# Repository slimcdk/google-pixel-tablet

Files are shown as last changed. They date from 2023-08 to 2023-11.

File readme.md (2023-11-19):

# Google Pixel Tablet

## Wall Mount (Version 2)



### Parts
7x M3x12mm countersunk. \
7x M3 nuts (<3mm thick). \
16x 12x5x3 cube magnets. \
2x M4 countersunk self tapping screw.

https://www.digikey.dk/da/products/detail/mill-max-manufacturing-corp/0853-0-15-20-82-14-11-0/2403178

## Base stand
### Disassembly

1) Rubber feet (E12) is held on with double sided adhesive. A gentle pull releases it.



2) Metal bracket (EW M2-1) is fastened with five Torx T7H screws (color coded magenta).



3) To EW M2-1 is main PCB attached. I assume this is the speaker driver. The 5-pin connector is for the speaker units. The smaller flex cable connects to the daughter PCB that mates with the tablet when it is docked.



4) Four Torx T6H screws (color coded green) fastens the magnetic face plate (TL-A2). The two in the front are easy to reach, however the two in the back are rather hard to reach. It requires a at least 70mm long screw driver (max 7mm) to reach them. The magnets are quite close and they will easily catch the screws at the bottom.



5) Face plate (TL-A2) lifts up.



6) The three main pieces.



### Magnet placements

The back has a total of eight magnet-pairs glued in place. Each pair has a thin metal backplate. I assume this is something that improves the magnetization.





A scan of the plate and a draw up in Freecad gives the exact locations of the magnets relative to the quick-disconnect port.



## Quick-disconnect connector

Disassembly and probing the connections reveals that the base stand forwards 12VDC to the tablet on the two outer most connector pads. The tablet will charge just fine if provided with 12VDC only.



The connector pair in the middle carry data signals. The protocol is still undetermined but it however seem like some sort of differential signalling.



Protocol is USB (maybe 2.0?), but is non-standard as logic levels are 3.3V and supply is 12V. It is undetermined if the circuitry is 5V tolerant. A connected ESP32-S3 appear as a serial device. The base station shows as Amlogic Korlan device.



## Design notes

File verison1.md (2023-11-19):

## Wall Mount Version 1



### Parts
7x M3x12mm countersunk. \
7x M3 nuts (<3mm thick). \
16x 12x5x3 cube magnets. \
2x M4 countersunk self tapping screw.

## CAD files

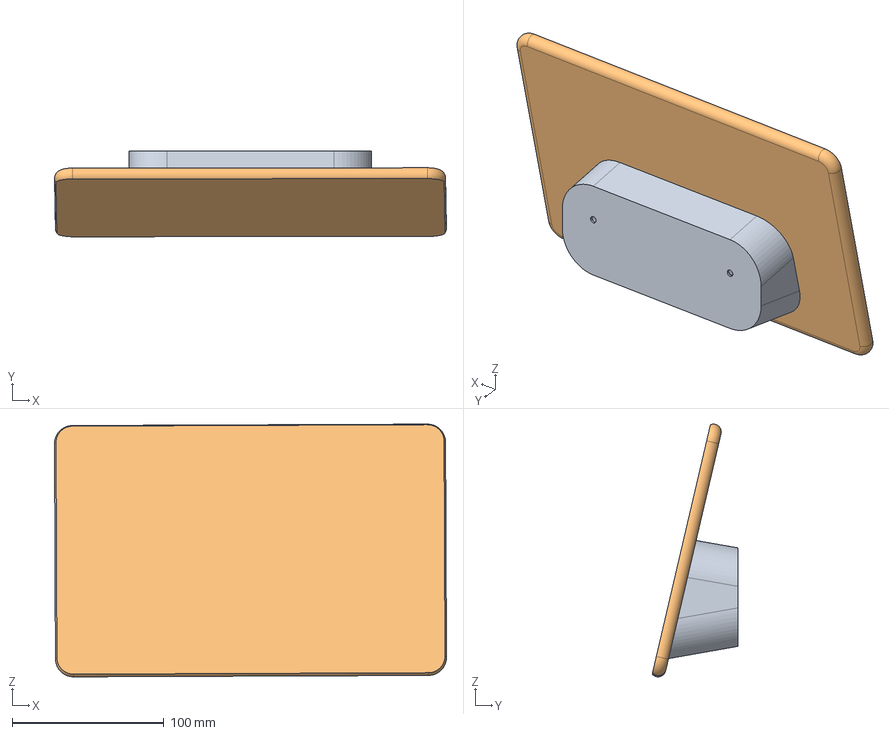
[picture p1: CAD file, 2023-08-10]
mechanics/assembly.FCStd
258.6 x 56.5 x 166.8 mm
wall-mount_001
pixel-tablet_001
M3x12-Screw
M3x12-Screw001
M3x12-Screw002
M3x12-Screw003
M3x12-Screw004
M3x12-Screw005
M3x12-Screw006

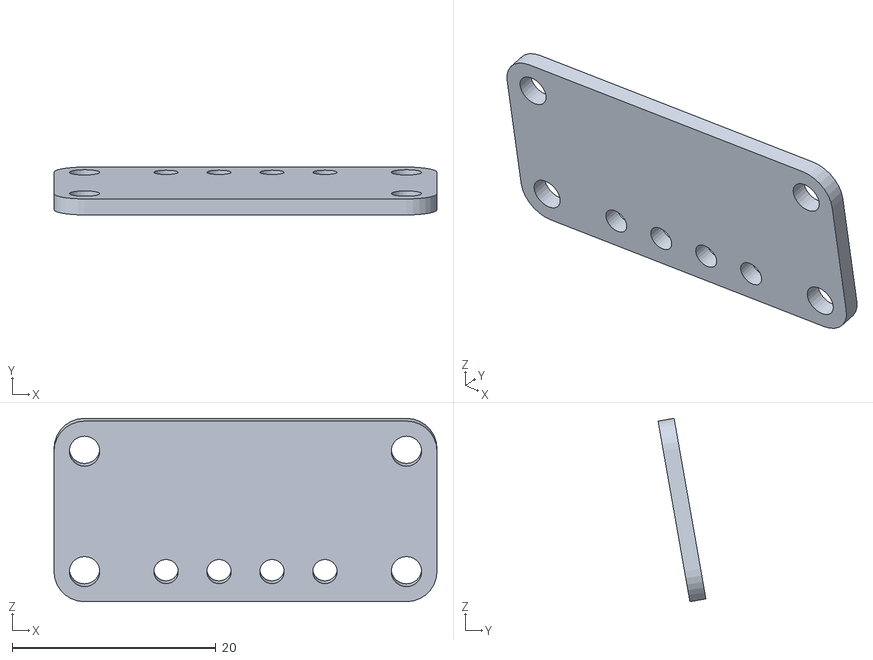
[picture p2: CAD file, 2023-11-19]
3d-print-files/v2-daughter-board.stl
37.6 x 4.70 x 18.0

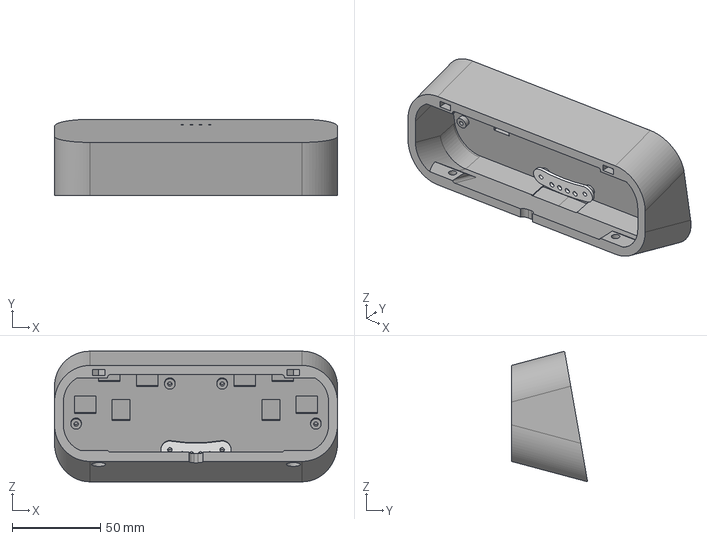
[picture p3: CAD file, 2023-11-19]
mechanics/wall-mount-v2.FCStd
160.0 x 43.1 x 73.9 mm
Housing

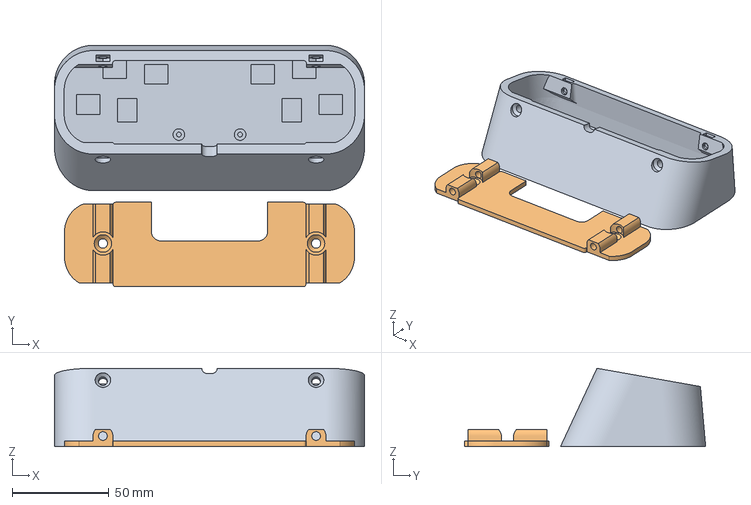
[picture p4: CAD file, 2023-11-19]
3d-print-files/v2-prusaslicer-setup.3mf
160.0 x 124.6 x 40.5 mm
v2-housing.stl
v2-mouting-plate.stl

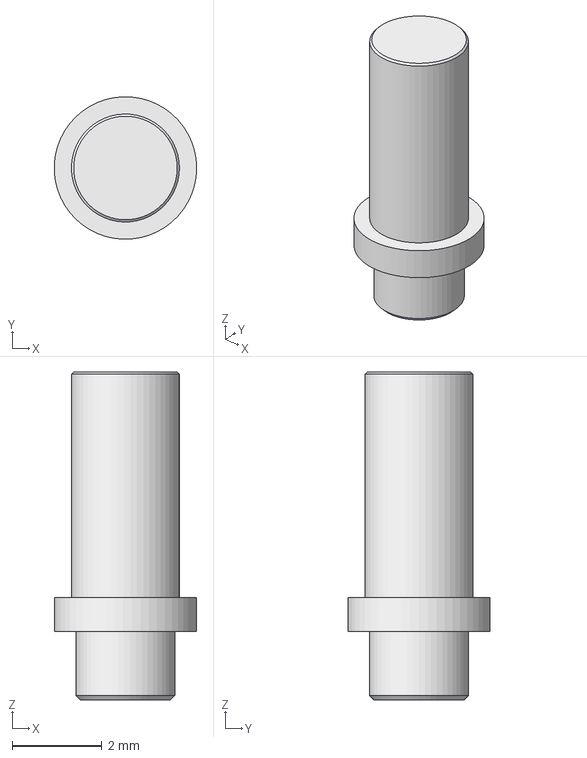
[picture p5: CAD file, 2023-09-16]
mechanics/pogo-pin.FCStd
3.18 x 3.18 x 7.32 mm

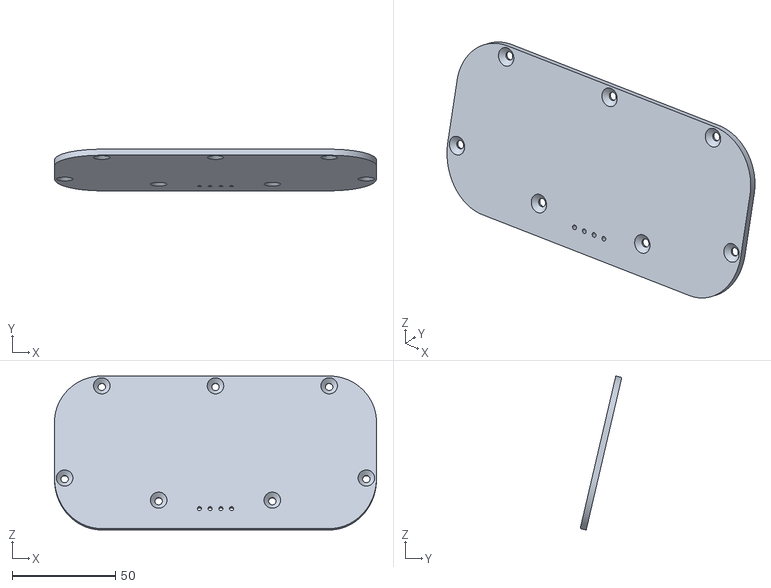
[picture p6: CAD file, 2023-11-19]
3d-print-files/v1-face-panel.stl
155.8 x 20.2 x 74.5

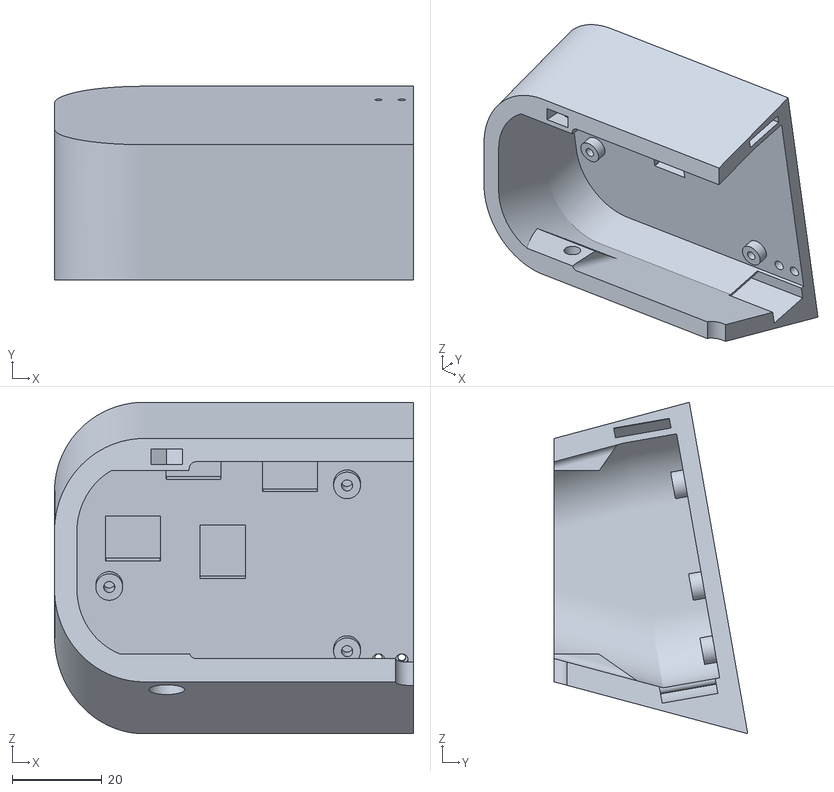
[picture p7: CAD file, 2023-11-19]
3d-print-files/wall-mount-v2-HousingPocket030.stl
80.0 x 43.1 x 73.9

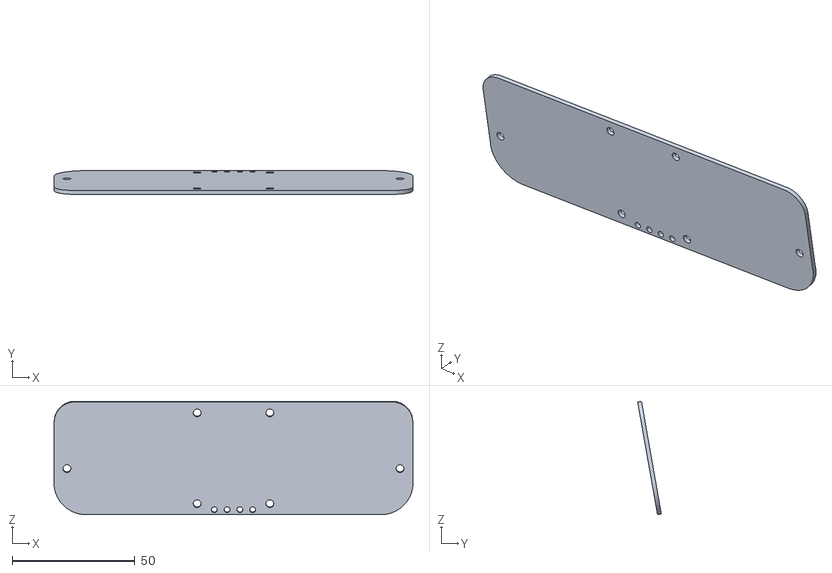
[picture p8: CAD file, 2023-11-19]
3d-print-files/wall-mount-v2-Board.stl
146.2 x 9.66 x 46.1

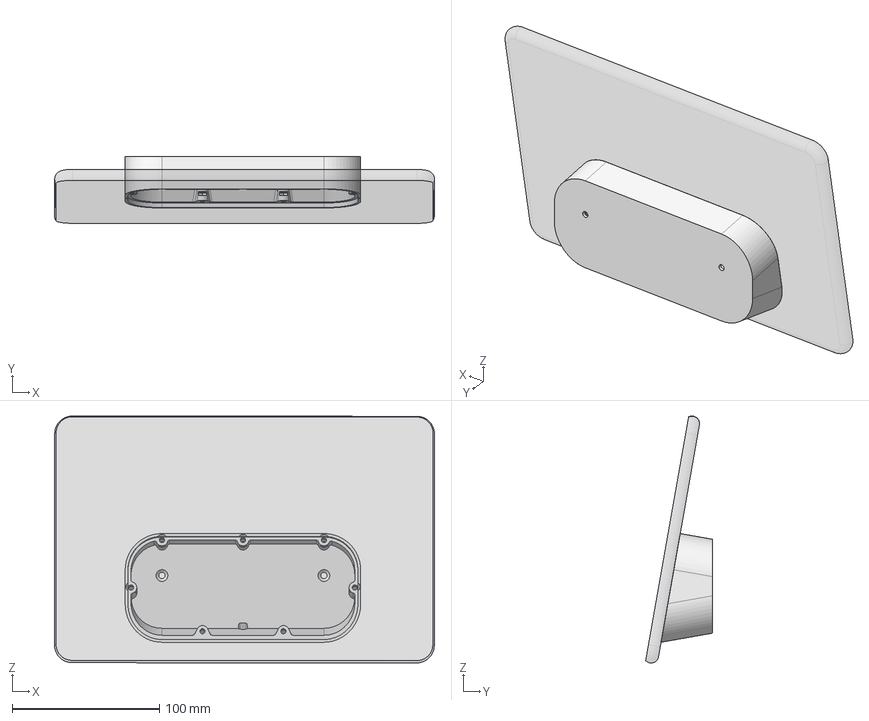
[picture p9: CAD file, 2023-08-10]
mechanics/wall-mount-proto.FCStd
258.1 x 45.3 x 167.8 mm
pixel-tablet_001
Base
Face Plate

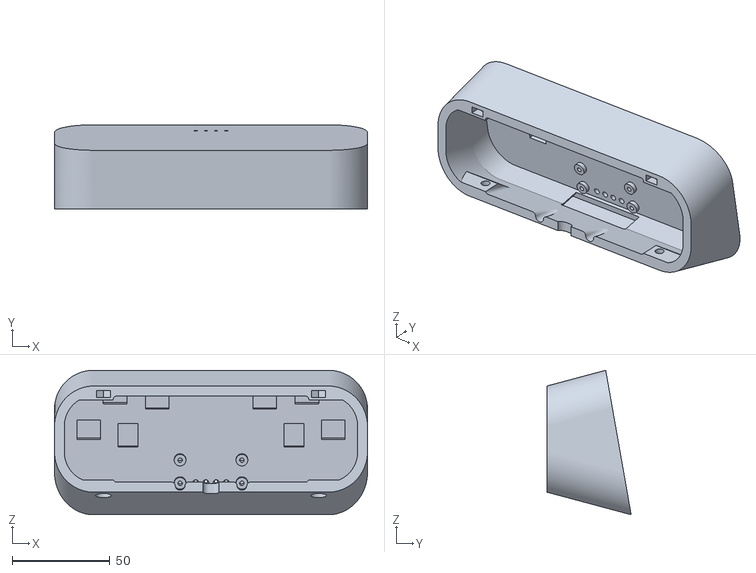
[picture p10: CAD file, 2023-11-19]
3d-print-files/v2-housing.stl
160.0 x 43.1 x 73.9

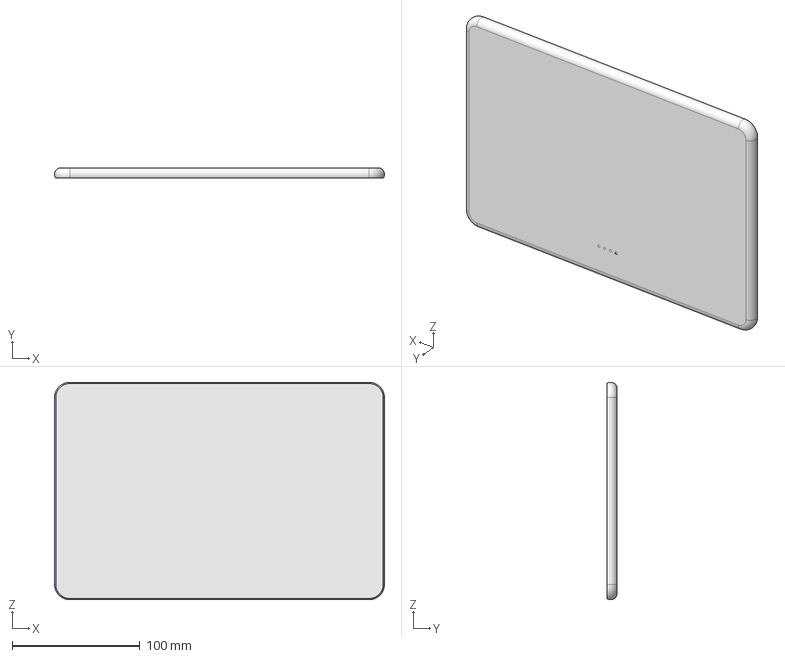
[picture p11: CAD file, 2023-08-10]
mechanics/pixel-tablet.FCStd
258.0 x 8.20 x 170.0 mm

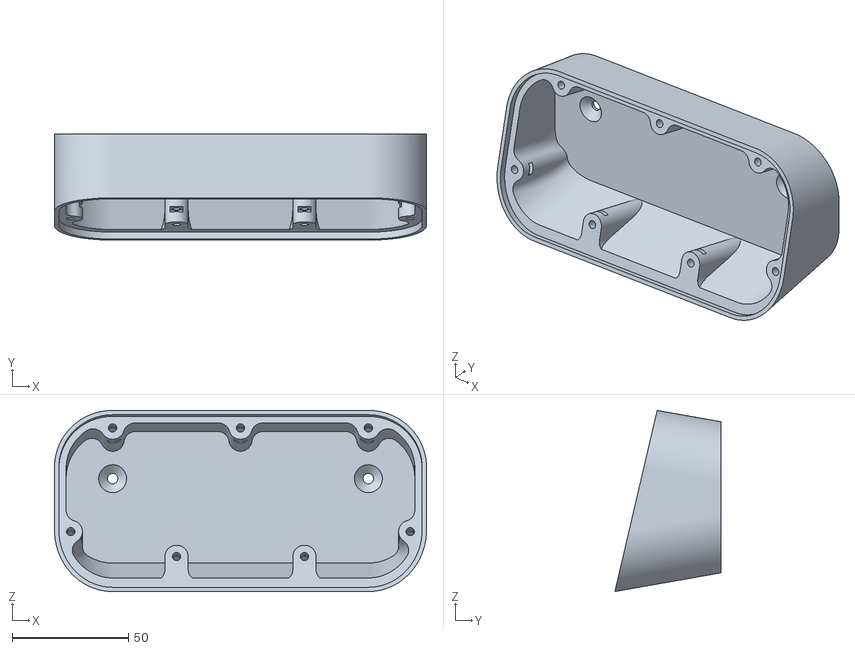
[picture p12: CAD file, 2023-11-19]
3d-print-files/v1-base.stl
160.0 x 45.7 x 77.9

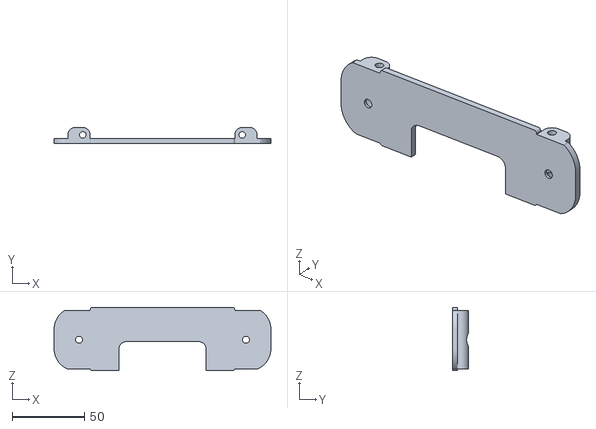
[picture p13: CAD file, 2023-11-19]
3d-print-files/v2-mouting-plate.stl
149.7 x 11.1 x 43.6

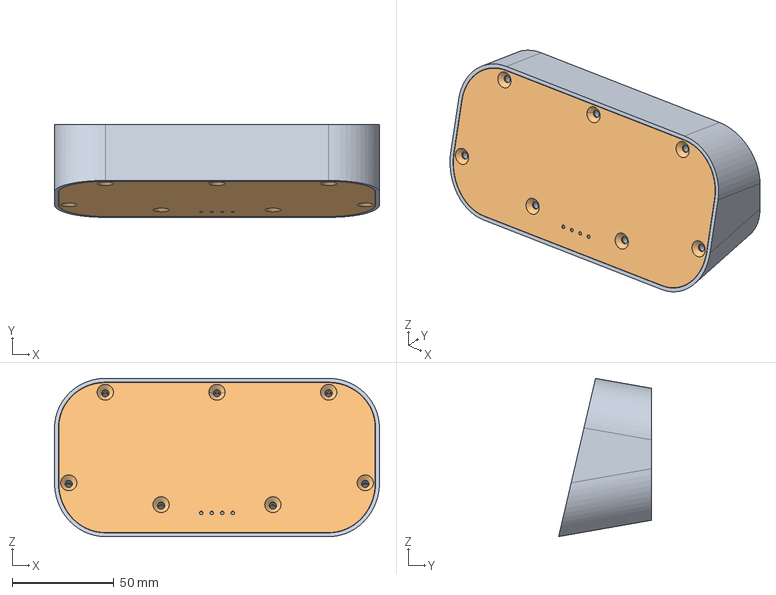
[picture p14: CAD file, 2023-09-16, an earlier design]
mechanics/wall-mount.FCStd
160.0 x 45.7 x 77.9 mm
Base
Face Panel

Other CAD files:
3d-print-files/wall-mount-v2-Housing.stl
3d-print-files/face-panel-pogo-test.stl
3d-print-files/v2-housing-test.stl

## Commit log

2023-08-10 disassembly with initial work of reverse engineering the magnet mounting and data signals
    [pixel-tablet.FCStd, wall-mount-proto.FCStd, wall-mount.FCStd]
2023-08-10 added cad view of current work for wall mount
    [assembly.FCStd, wall-mount.FCStd]
2023-08-10 sketching up some electronics
    [electronics.kicad_pcb, electronics.kicad_sch]
2023-09-16 version 2; 144led/m strip
    [pogo-pin.FCStd, wall-mount-v2-test.stl, wall-mount-v2.FCStd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]
2023-11-19 adding current prototypes
    [electronics.kicad_pcb, electronics.kicad_sch, face-panel-pogo-test.stl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]
